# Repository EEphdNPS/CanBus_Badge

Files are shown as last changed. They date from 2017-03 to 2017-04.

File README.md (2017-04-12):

# CanBus_Badge
As we develop a badge for the upcoming event, I will post my eagle files, bill of materials, and source code here.

I developed the board and schematic in Eagle 7.6.0 light.

This board is based on Microchip's AN212 reference design (http://ww1.microchip.com/downloads/en/AppNotes/00212c.pdf)

Overview: The objective of this project is to build a controller area network (CAN) node that can be used during our upcoming hack-a-thon event. Each CAN node is powered by one 9 volt battery. The CAN node has one input and one output. The input is a photoresistor (R12) that is part of a voltage divider. The PIC microcontroller does an analog to digital conversion based on the output of the voltage divider. The CAN node output is a PWM-driven LED (add the part number from the BOM and schematic). The CAN ID of the node is based on the dip switches. The first two switches define the CAN ID when the node transmits the result of the A/D conversion. The last two switches determine which CAN ID the node will receive. The results of A/D conversion are transmitted onto the CAN bus and received by the proper CAN node. The CAN node uses this value to set the pulse width of the on pulse.

5V power regulation:
The current design of the badge uses a 7805 chip to take the 9V battery output and produce 5V for the badge to run. As a note, because the node is powered at 5V, the CAN bus high and low will have a neutral value of 2.5V and the CAN bus high will be 5V and the CAN bus low will be 0V. Added to the power regulation portion of the design is a momentary push button that will indicate whether the badge is on or off. I have not calculated the life of the battery in this application, but during the development of the badge, I've only used one battery and I used one batter to run both nodes that I built. 

PIC 16F876:
The PIC microprocessor is the main chip on the board. The code is (will be) uploaded. The PIC talks to the MCP2515 chip via a SPI interface (pins 3-chip select, 14-SCK, 15-SDI, 16-SDO). Each line of the SPI interface has a test point, which we can use to access the SPI messages during the hack-a-thon. The PIC has one pin (pin 2) for the A/D conversion of the voltage divider. It has one pin (pin 13) as the PWM output. The chip receives a 4 MHz clock signal on pins 9 and 10. Pin 21 on the PIC is connected to the interrupt pin (pin 12) on the MCP2515. Pins 25 and 26 are connected are connected to the receive buffers on the MCP2515. Pins 11, 12, 17, 18 are connected to the DIP switches and are read to determine the transmit CAN ID and which CAN ID will be received. 

MCP2515:
The MCP2515 is the CAN controller chip and handles all CAN messaging. Pins 1 and 2 are connected to the MCP2551. The LEDs off of these lines are used as a visual indication that there is communication between these two chips. There are also test points added to these lines to access the messages being transmitted and received between the two chips. This chip operates with a 16 MHz oscillator on pins 7 and 8. I believe this frequency determines the bit rate on the CAN bus. I added a momentary button to the reset pin because occasionally the chip won't go into normal mode from startup mode. After reading the documentation, the chip needs a bus to be connected before going into normal mode. The reset button let you turn on the node first and then connect it to the bus. Once the bus is connected, I've found that one press of the reset button allows the chip to transition.

MCP2551:
The MCP2551 is a simple chip that interfaces with the CAN bus. This chip is probably not actually needed in this design. I have not tested whether or not it is required. We could probably skip it and connect the MCP2515 directly to another MCP2515 on another node. Pin 6 in the CAN low pin. Pin 7 is the CAN high pin. Pin 8 must be connected to ground via 10K ohm resistor. This pin sets the various modes of the MCP2551 chip. Without this resistor the CAN nodes will not communicate properly. 

CAN Bus:
To build the CAN bus, two 120 ohm resistors are required. These two resistors connect the high and low CAN bus wires at the termination of each end of the bus. At this point, I do not know a limit on the number of nodes that can be added to the bus without significant collisions. I have tested two nodes. If we have more, we could determine the max number that can be added. After trying several different configurations, I've settled on directly connecting the badges. There is no need for the 120 ohm resistors.

I've used the CanaKit UK1300 to program the PICs that I used on my breadboard. The ICSP works on the breadboard I've been developing from. I was not able to test it with Rev 1.0. I used the PICKit 3.

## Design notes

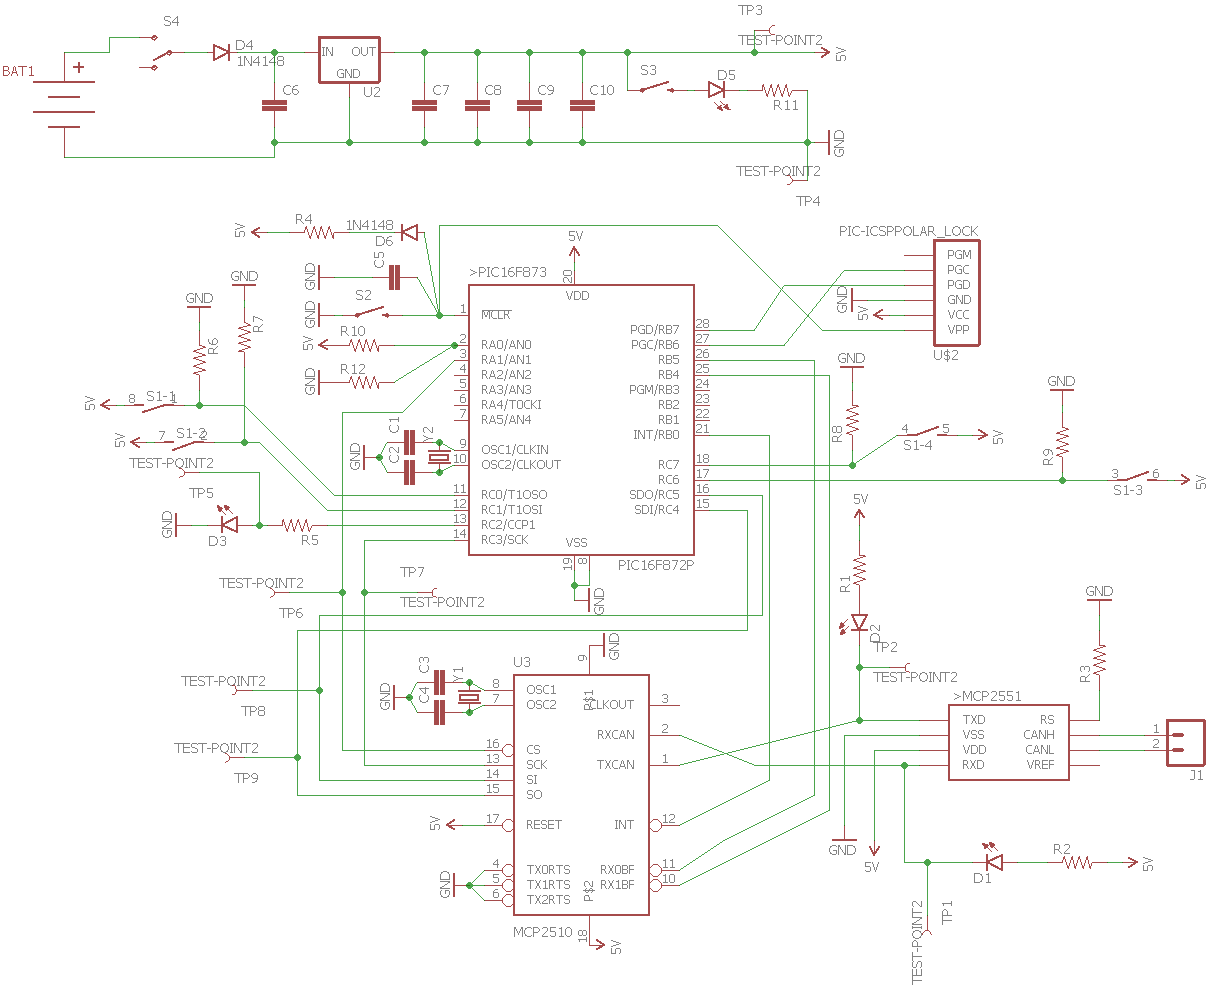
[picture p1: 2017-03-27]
HACKtheMACHINE_schematic.png

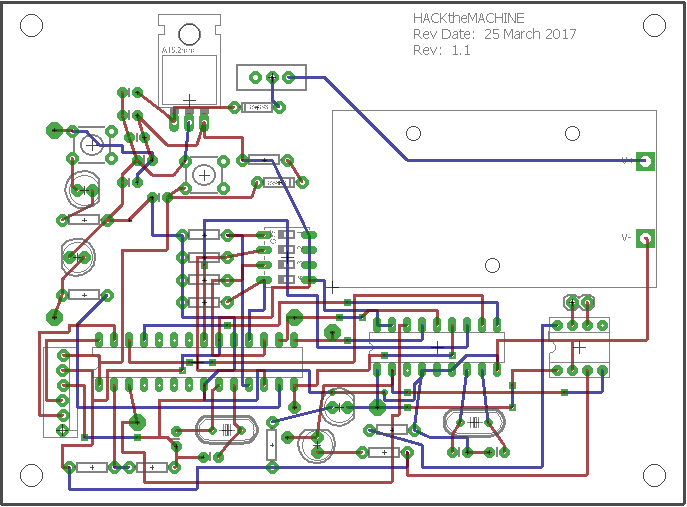
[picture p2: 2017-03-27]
HACKtheMACHINE_board.png

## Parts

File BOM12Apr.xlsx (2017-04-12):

DISCLAIMER: I used whatever parts I had laying around the house. I've listed specific products, but that is only to help with the build. For example, any generic 18 pF capacitor can be used. I also used only digikey to make it easier to find the parts.
Part | Value | Device | Package | Description | MF | MPN | Digi-Key part number | Link to product
BAT1 | N/A | BC9VPC | BC9VPC | 9V board-mount battery cradle | MPD | BC9VPC | BC9VPC-ND | http://www.digikey.com/product-detail/en/mpd-memory-protection-devices/BC9VPC/BC9VPC-ND/257747
C1 | 18 pF | CAPPTH | CAP-PTH-SMALL | 18 pF Ceramic Capacitor | Vishay | K180J15C0GF5TL2 | BC1004TR-ND | https://www.digikey.com/product-detail/en/vishay-bc-components/K180J15C0GF5TL2/BC1004TR-ND/286458
C2 | 18 pF | CAPPTH | CAP-PTH-SMALL | 18 pF Ceramic Capacitor | Vishay | K180J15C0GF5TL3 | BC1004TR-ND | https://www.digikey.com/product-detail/en/vishay-bc-components/K180J15C0GF5TL2/BC1004TR-ND/286458
C3 | 18 pF | CAPPTH | CAP-PTH-SMALL | 18 pF Ceramic Capacitor | Vishay | K180J15C0GF5TL4 | BC1004TR-ND | https://www.digikey.com/product-detail/en/vishay-bc-components/K180J15C0GF5TL2/BC1004TR-ND/286458
C4 | 18 pF | CAPPTH | CAP-PTH-SMALL | 18 pF Ceramic Capacitor | Vishay | K180J15C0GF5TL5 | BC1004TR-ND | https://www.digikey.com/product-detail/en/vishay-bc-components/K180J15C0GF5TL2/BC1004TR-ND/286458
C5 | 0.001 μF | CAPPTH | CAP-PTH-SMALL | 0.001 μF Ceramic Capacitor | Kemet | C320C102K5R5TA | 399-9769-ND | https://www.digikey.com/product-detail/en/kemet/C320C102K5R5TA/399-9769-ND/3726158
C6 | 0.1 μF | CAPPTH | CAP-PTH-SMALL | 0.1 μF Electrolytic Cpacitor | Nichicon | UVR2A0R1MDD | 493-1136-ND | https://www.digikey.com/product-detail/en/nichicon/UVR2A0R1MDD/493-1136-ND/588877
C7 | 10 μF | CAPPTH | CAP-PTH-SMALL | 10 μF Electrolytic Cpacitor | Nichicon | UVR1E100MDD6TP | 493-12772-1-ND | https://www.digikey.com/product-detail/en/nichicon/UVR1E100MDD6TP/493-12772-1-ND/4328365
C8 | 102 pF | CAPPTH | CAP-PTH-SMALL | 102 pF Ceramic Capacitor | Vishay | K101J15C0GF5TL2 | BC1013CT-ND | https://www.digikey.com/product-detail/en/vishay-bc-components/K101J15C0GF5TL2/BC1013CT-ND/286635
C9 | 102 pF | CAPPTH | CAP-PTH-SMALL | 102 pF Ceramic Capacitor | Vishay | K101J15C0GF5TL3 | BC1013CT-ND | https://www.digikey.com/product-detail/en/vishay-bc-components/K101J15C0GF5TL2/BC1013CT-ND/286635
C10 | 102 pF | CAPPTH | CAP-PTH-SMALL | 102 pF Ceramic Capacitor | Vishay | K101J15C0GF5TL4 | BC1013CT-ND | https://www.digikey.com/product-detail/en/vishay-bc-components/K101J15C0GF5TL2/BC1013CT-ND/286635
D1 | N/A | LED5MM | LED5MM | Red LED | Cree | C503B-RCN-CW0Z0AA1 | C503B-RCN-CW0Z0AA1-ND | https://www.digikey.com/product-detail/en/cree-inc/C503B-RCN-CW0Z0AA1/C503B-RCN-CW0Z0AA1-ND/1922930
D2 | N/A | LED5MM | LED5MM | Green LED | Cree | C503B-GCS-CY0C0791 | C503B-GCS-CY0C0791-ND | https://www.digikey.com/product-detail/en/cree-inc/C503B-GCS-CY0C0791/C503B-GCS-CY0C0791-ND/1922941
D3 | N/A | LED5MM | LED5MM | White LED | Cree | C513A-WSS-CY0Z0231 | C513A-WSS-CY0Z0231-ND | https://www.digikey.com/product-detail/en/cree-inc/C513A-WSS-CY0Z0231/C513A-WSS-CY0Z0231-ND/5120069
D4 | N/A | DIODEKIT | DIODE-1N4148-KIT | Diode | Sanken | EM01ZV1 | EM01ZV1CT-ND | https://www.digikey.com/product-detail/en/sanken/EM01ZV1/EM01ZV1CT-ND/4572558
D5 | N/A | LED5MM | LED5MM | Blue LED | Cree | C503B-BCN-CV0Z0461 | C503B-BCN-CV0Z0461-ND | https://www.digikey.com/product-detail/en/cree-inc/C503B-BCN-CV0Z0461/C503B-BCN-CV0Z0461-ND/1922945
D6 | N/A | DIODEKIT | DIODE-1N4148-KIT | Diode | Sanken | EM01ZV1 | EM01ZV1CT-ND | https://www.digikey.com/product-detail/en/sanken/EM01ZV1/EM01ZV1CT-ND/4572558
IC1 | N/A | PIC16F872P | DIL28-3 | MICROCONTROLLER | MICROCHIP | PIC16F873-20/SP | PIC16F873-20/SP-ND | https://www.digikey.com/products/en?keywords=PIC16F873-20%2FSP
J1 | 2 pin header | M02PTH | 1X02 | Standard 2-pin 0.1 header | Sullins connector solutions | PPTC021LFBN-RC | S7000-ND | https://www.digikey.com/product-detail/en/sullins-connector-solutions/PPTC021LFBN-RC/S7000-ND/810142
R1 | 1k Ω | RESISTOREZ | AXIAL-0.3EZ | 1k Ω resistor
R2 | 1k Ω | RESISTOREZ | AXIAL-0.3EZ | 1k Ω resistor
R3 | 10k Ω | RESISTOREZ | AXIAL-0.3EZ | 10k Ω resistor
R4 | 47k Ω | RESISTOREZ | AXIAL-0.3EZ | 47k Ω resistor
R5 | 1k Ω | RESISTOREZ | AXIAL-0.3EZ | 1k Ω resistor
R6 | 10k Ω | RESISTOREZ | AXIAL-0.3EZ | 10k Ω resistor
R7 | 10k Ω | RESISTOREZ | AXIAL-0.3EZ | 10k Ω resistor
R8 | 10k Ω | RESISTOREZ | AXIAL-0.3EZ | 10k Ω resistor
R9 | 10k Ω | RESISTOREZ | AXIAL-0.3EZ | 10k Ω resistor
R10 | 47k Ω | RESISTOREZ | AXIAL-0.3EZ | R10 and R12 are part of a voltage divider. Adjust R10 to get a good dynamic range based on the range of R12.
R11 | 1k Ω | RESISTOREZ | AXIAL-0.3EZ | 1k Ω resistor
R12 | ~300 to 50k Ω | RESISTORAXIAL-0.3 | AXIAL-0.3 | Photoresistor Optoresistor Photo Light Sensitive Resistor | Luna Optoelectronics | PDV-P8103 | PDV-P8103-ND | https://www.digikey.com/product-detail/en/luna-optoelectronics/PDV-P8103/PDV-P8103-ND/480610
S1 | Dip Switch | DIP04S | DIP04S | 4 switches set the receiver and transmit CAN ID | CTS | 206-4ST | CT2064ST-ND | https://www.digikey.com/product-detail/en/cts-electrocomponents/206-4ST/CT2064ST-ND/20774
S2 | Momentary Push Button | SWITCH-MOMENTARY-2PTH | TACTILE-PTH | Tactile push button | TE Connectivity ALCOSWITCH Switches | 1825910-6 | 450-1650-ND | https://www.digikey.com/product-detail/en/te-connectivity-alcoswitch-switches/1825910-6/450-1650-ND/1632536
S3 | Momentary Push Button | SWITCH-MOMENTARY-2PTH | TACTILE-PTH | Tactile push button | TE Connectivity ALCOSWITCH Switches | 1825910-6 | 450-1650-ND | https://www.digikey.com/product-detail/en/te-connectivity-alcoswitch-switches/1825910-6/450-1650-ND/1632536
S4 | SPDT switch | SWITCH-SPDTKIT | SWITCH-SPDT_KIT | On/Off Switch | E-Switch | EG1218 | EG1903-ND | https://www.digikey.com/product-detail/en/e-switch/EG1218/EG1903-ND/101726
S5 | Momentary Push Button | SWITCH-MOMENTARY-2PTH | TACTILE-PTH | Tactile push button | TE Connectivity ALCOSWITCH Switches | 1825910-6 | 450-1650-ND | https://www.digikey.com/product-detail/en/te-connectivity-alcoswitch-switches/1825910-6/450-1650-ND/1632536
TP1 | TEST-POINT2 | TEST-POINT2 | PAD.02X.02 | Receive CAN between MCP2515 and MCP2551
TP2 | TEST-POINT2 | TEST-POINT2 | PAD.02X.02 | Transmit CAN between MCP2515 and MCP2551
TP3 | TEST-POINT2 | TEST-POINT2 | PAD.02X.02 | 5 volt/power test point
TP4 | TEST-POINT2 | TEST-POINT2 | PAD.02X.02 | Ground test point
TP5 | TEST-POINT2 | TEST-POINT2 | PAD.02X.02 | PWM output test point
TP6 | TEST-POINT2 | TEST-POINT2 | PAD.02X.02 | Chip Select Line between PIC and MCP2515
TP7 | TEST-POINT2 | TEST-POINT2 | PAD.02X.02 | Clock between PIC and MCP2515
TP8 | TEST-POINT2 | TEST-POINT2 | PAD.02X.02 | Slave Input between PIC and MCP2515
TP9 | TEST-POINT2 | TEST-POINT2 | PAD.02X.02 | Slave Output between PIC and MCP2515
U$1 | MCP2551 | MCP2551 | DIL8 | CAN controller with SPI interface to any MCU. | MICROCHIP | MCP2551-I/P | MCP2551-I/P-ND | https://www.digikey.com/product-detail/en/microchip-technology/MCP2551-I-P/MCP2551-I-P-ND/509453
U$2 | 6 pin header | ICSP header | 6-pin header | Standard 6-pin 0.1 header | Samtec | SSA-106-S-T | SAM1122-06-ND | https://www.digikey.com/product-detail/en/samtec-inc/SSA-106-S-T/SAM1122-06-ND/1105810
U2 | 5 volt regulator | V_REG_78XXSIDE | L7805 | Voltage Regulator | STMicroelectronics | L7805CV | 497-1443-5-ND | https://www.digikey.com/product-detail/en/stmicroelectronics/L7805CV/497-1443-5-ND/585964
U3 | MCP2515 | MCP2515 | DIL18 | CAN controller with SPI interface to any MCU. | MICROCHIP | MCP2515-I/P | MCP2515-I/P-ND | https://www.digikey.com/product-detail/en/microchip-technology/MCP2515-I-P/MCP2515-I-P-ND/593000
Y1 | 16 MHz | CRYSTALHC49UV | HC49U-V | Oscillator for MCP2510 | ECS inc | ECS-160-20-4X-DU | XC1925-ND | https://www.digikey.com/product-detail/en/ecs-inc/ECS-160-20-4X-DU/XC1925-ND/2781930
Y2 | 4 MHz | CRYSTALHC49UV | HC49U-V | Oscillator for PIC | ECS inc | ECS-40-18-4XEN | XC1735-ND | https://www.digikey.com/product-detail/en/ecs-inc/ECS-40-18-4XEN/XC1735-ND/2213755

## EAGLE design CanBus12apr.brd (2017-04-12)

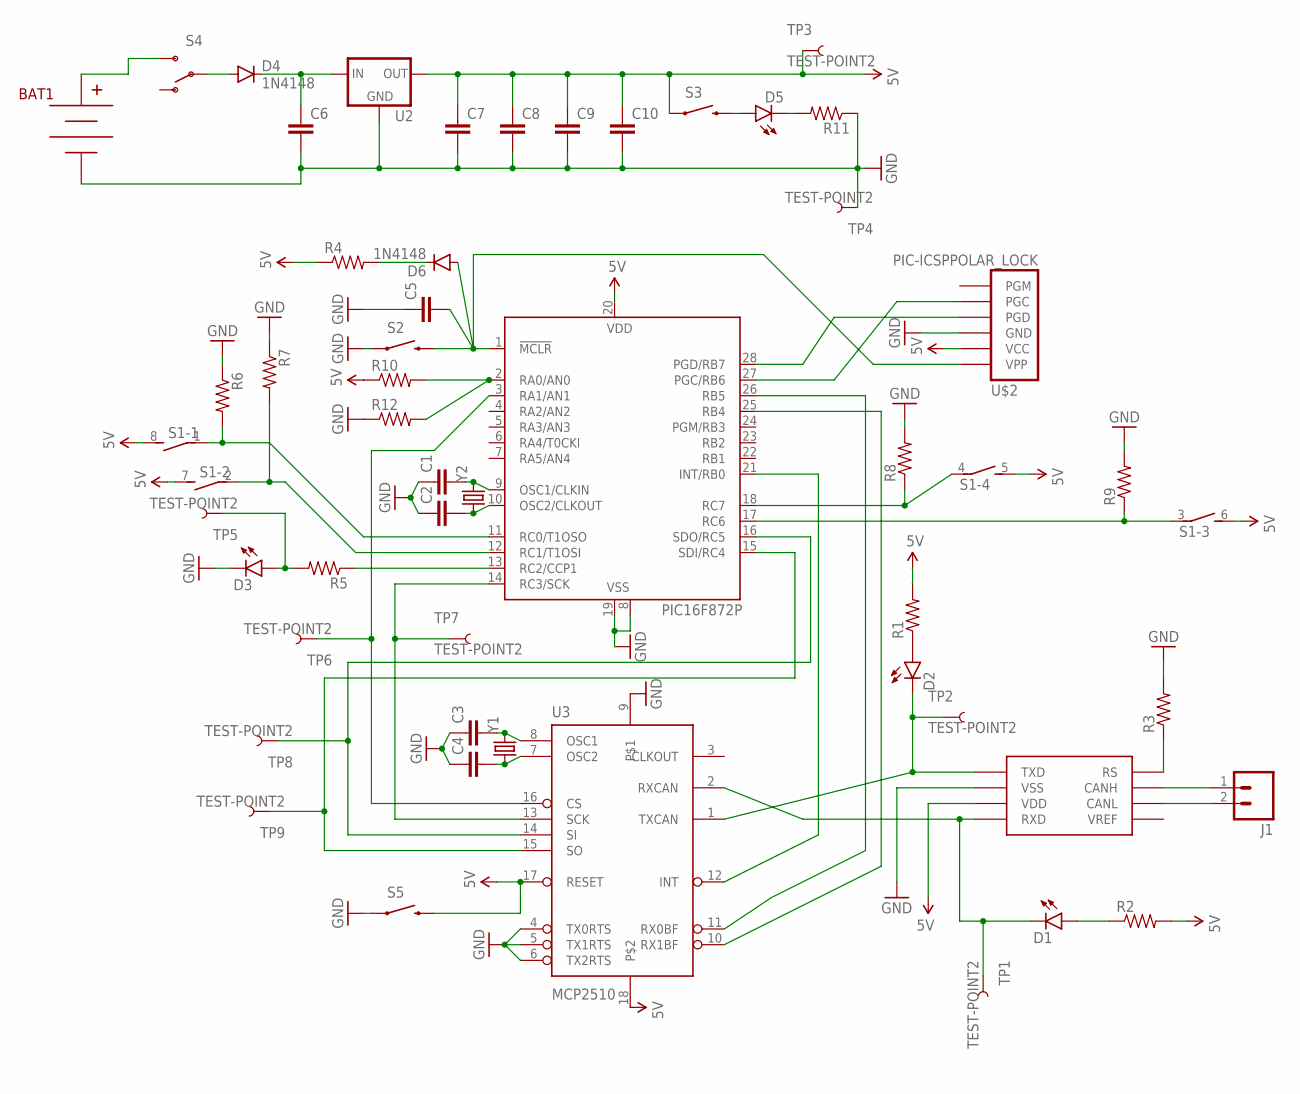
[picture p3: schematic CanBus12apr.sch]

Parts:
BAT1: BC9VPC
C1, C2, C3, C4, C5, C6, C7, C8, C9, C10: CAPPTH; CAP-PTH-SMALL
D1, D2, D3, D5: LED5MM
D4, D6: 1N4148; DIODE-1N4148-KIT
IC1: PIC16F872P; DIL28-3
J1: M02PTH; 1X02
R1, R2, R3, R4, R5, R6, R7, R8, R9, R10, R11: RESISTOREZ; AXIAL-0.3EZ
R12: RESISTORAXIAL-0.3; AXIAL-0.3
S1: DIP04S
S2, S3, S5: SWITCH-MOMENTARY-2PTH; TACTILE-PTH
S4: SWITCH-SPDTKIT; SWITCH-SPDT_KIT
TP1, TP2, TP3, TP4, TP5, TP6, TP7, TP8, TP9: TEST-POINT2; PAD.02X.02
U2: V_REG_78XXSIDE; 78XXL
U3: MCP2510; DIL18
U$1: MCP2551
U$2: PIC-ICSPPOLAR_LOCK; MOLEX-1X6_LOCK
Y1, Y2: CRYSTALHC49UV; HC49U-V

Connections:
5V: C7.1, C8.1, C9.1, C10.1, IC1.20 (VDD), R1.P$2 (2), R2.P$2 (2), R4.P$1 (1), R10.P$1 (1), S1.5 (2), S1.6 (2), S1.7 (2), S1.8 (2), S3.1, S5.3 (2), TP3.P$1, U2.OUT, U3.17 (RESET), U3.18, U$1.VDD, U$2.5 (VCC)
GND: BAT1.V-, C1.1, C2.1, C3.1, C4.1, C5.1, C6.2, C7.2, C8.2, C9.2, C10.2, D3.K (C), IC1.8 (VSS), IC1.19 (VSS), R3.P$2 (2), R6.P$1 (1), R7.P$1 (1), R8.P$2 (2), R9.P$2 (2), R11.P$1 (1), R12.P$1 (1), S2.1, S5.1, TP4.P$1, U2.GND, U3.4 (TX0RTS), U3.5 (TX1RTS), U3.6 (TX2RTS), U3.9, U$1.VSS, U$2.4 (GND)
unnamed: D1.K (C), TP1.P$1, U3.2 (RXCAN), U$1.RXD
unnamed: D2.K (C), TP2.P$1, U3.1 (TXCAN), U$1.TXD
unnamed: D2.A, R1.P$1 (1)
unnamed: D1.A, R2.P$1 (1)
unnamed: IC1.21 (INT/RB0), U3.12 (INT)
unnamed: IC1.26 (RB5), U3.11 (RX0BF)
unnamed: IC1.25 (RB4), U3.10 (RX1BF)
unnamed: IC1.11 (RC0/T1OSO), R6.P$2 (2), S1.1
unnamed: R3.P$1 (1), U$1.RS
unnamed: IC1.2 (RA0/AN0), R10.P$2 (2), R12.P$2 (2)
unnamed: C3.2, U3.8 (OSC1), Y1.2
unnamed: C4.2, U3.7 (OSC2), Y1.1
unnamed: C1.2, IC1.9 (OSC1/CLKIN), Y2.2
unnamed: C2.2, IC1.10 (OSC2/CLKOUT), Y2.1
unnamed: IC1.14 (RC3/SCK), TP7.P$1, U3.13 (SCK)
unnamed: IC1.16 (SDO/RC5), TP8.P$1, U3.14 (SI)
unnamed: IC1.15 (SDI/RC4), TP9.P$1, U3.15 (SO)
unnamed: IC1.3 (RA1/AN1), TP6.P$1, U3.16 (CS)
unnamed: C5.2, D6.A, IC1.1 (!MCLR!), S2.3 (2), U$2.6 (VPP)
unnamed: IC1.13 (RC2/CCP1), R5.P$1 (1)
unnamed: D3.A, R5.P$2 (2), TP5.P$1
unnamed: IC1.27 (PGC/RB6), U$2.2 (PGC)
unnamed: IC1.12 (RC1/T1OSI), R7.P$2 (2), S1.2 (1)
unnamed: IC1.17 (RC6), R9.P$1 (1), S1.3 (1)
unnamed: IC1.18 (RC7), R8.P$1 (1), S1.4 (1)
unnamed: BAT1.V+, S4.3 (S)
unnamed: C6.1, D4.C, U2.IN
unnamed: D5.K (C), R11.P$2 (2)
unnamed: D4.A, S4.2
unnamed: D5.A, S3.3 (2)
unnamed: J1.1, U$1.CANH
unnamed: J1.2, U$1.CANL
unnamed: IC1.28 (PGD/RB7), U$2.3 (PGD)
unnamed: D6.C, R4.P$2 (2)

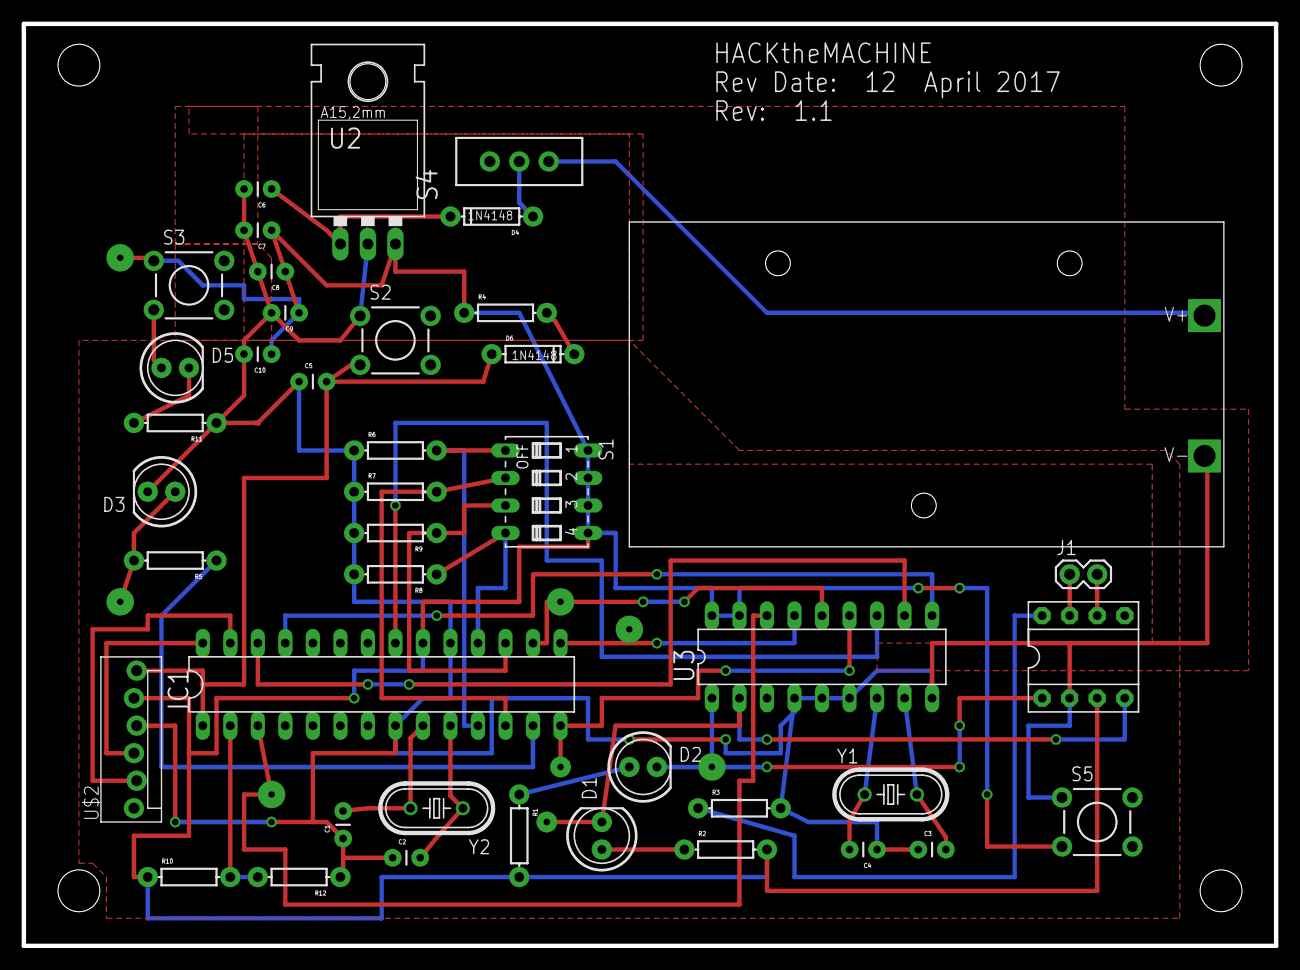
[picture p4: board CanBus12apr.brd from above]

Board: 2 copper layers, 115.6 x 85.1 mm, 51 parts (0 on the bottom side), 36 nets.

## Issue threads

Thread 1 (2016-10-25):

Eagle Design Review

zacsketches, 2016-10-25:
James, please take a look at the board and schematic for this project.

Zac

Closed 2017-03-21.

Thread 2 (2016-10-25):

README needs to be more descriptive

zacsketches, 2016-10-25:
Tom, I think it would help James if the README was written from the perspective of someone completely new to this board. Right now it requires some inside knowledge of our conversations about how to design it.

Thoughts?

EEphdNPS, 2016-10-25:
Can do.

EEphdNPS, 2016-10-27:
I've added a lot more detail. Let me know if this is good enough.

Closed 2016-10-27.

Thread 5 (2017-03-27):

Eliminate the 9 volt battery

EEphdNPS, 2017-03-27:
I would like to use smaller, coin batteries like the CR2032.

EEphdNPS, 2017-04-03:
I bought a battery holder for the CR2032. I'm waiting on the batteries to arrive.

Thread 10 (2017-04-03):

add momentary button to reset mcp2515

EEphdNPS, 2017-04-03:
Sometimes the canbus hangs and needs to be reset. A reset button on the mcp2515 will probably do the trick.

Closed 2017-04-12.

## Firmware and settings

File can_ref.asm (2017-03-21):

;*******************************************************************
; Microchip CAN Reference Design
;
; Mike Richitelli
; Diversified Engineering
; 283 Indian River Road
; Orange, CT 06477
; (203)799-7875 fax(203)799-7892
; WWW.DIVERSIFIEDENGINEERING.NET 
;
;*******************************************************************
;*******************************************************************

          TITLE " CAN_Ref Design "

;*******************************************************************

dVersion       equ  1
dRelease       equ  5

;======================================================================
; Transmits CAN message every 131 mSec.  Message contains two data bytes
;         that represent a 12 bit value with least significant byte
;         sent first.
; Cycles between three outputs:
;         Pot:  Value goes from 0 to 0xFF0 as Pot is turned clockwise.
;               ID is selected from DIP switches #3 and #4 as follows:
;                   #3 #4  ID
;                   0  0   transmission disabled 
;                   0  1   0x100
;                   1  0   0x200
;                   1  1   0x300
;
;         Push button switch: Switch open => 0, Switch closed => 0xFFF   
;               ID is Pot ID + 0x010
;
;         CdS:  Value goes from 0 to 0xFF0 as Pot is turned clockwise.
;               ID is Pot ID + 0x020
;
; CAN messages received are assumed to be 12 bit data sent as two bytes, 
;         least significant byte first.
;
;         The base ID for receiving CAN messages is specified by DIP 
;         switches #1 and #2:
;                   #1 #2  ID
;                   0  0   0x000
;                   0  1   0x100
;                   1  0   0x200
;                   1  1   0x300
;
;         Lamp: If the message ID matches the ID selected by the DIP 
;               switches the 12 bit data is used to generate a PWM output 
;               where a 0 value gives a zero duty cycle and 0xFFF generates 
;               a 100% duty cycle.  The lamp output is proportional to
;               the duty cycle.
;               ID is Base ID
;
;         LED: On if value received is >= 0x800 and off if < 0x800.
;               ID is Base ID + 0x010
;
;======================================================================

;----- PIC16F876 Micro -----;

          LIST P=16F876
          LIST r=dec,x=on,t=off

#include "P16F876.INC"

  __CONFIG _BODEN_ON&_CP_OFF&_WRT_ENABLE_ON&_PWRTE_ON&_WDT_OFF&_HS_OSC&_DEBUG_OFF&_CPD_OFF&_LVP_OFF
  __IDLOCS (dVersion<<8)|dRelease  ; version: vvrr , vv- version, rr - release

;---------------------------;

#include "MACROS16.INC"
#include "MCP2510.INC"

;          errorlevel 0,-306,-302,-305

 
;******** constants

;Crystal freq 4.00 MHz, Fosc/4 = 1 uS
;
; Timer 1: Uses no prescale => Tic is 1 uSec
;       8 bit rollover 256 uSec
;       16 bit rollover 65.536 mSec

;   8 bit timers
;    TMR1L: 1 uSec tics with maximum of 1/2 rollover = 128 uSec maximum
;    TMR1H: 256 uSec tics with maximum of 1/2 rollover = 32.768 msec maximum



;======================================================================

;************************
; A/D selection ( value of ADCON0 )

#define dA2DRA0     B'01000000'         ; fosc/8 clk, RA0, A/D off
#define dA2DRA3     B'01011000'         ; fosc/8 clk, RA3, A/D off


;************************
; special function defines

#define _SSPEN      SSPCON,SSPEN        ; SPI enable

;************************

;; General control flags definitions

#define tbWork          bGenFlags1,0   ; working bit
#define tbReset         bGenFlags1,1   ; must reset 
#define tbNewSPI        bGenFlags1,2   ; new SPI data available
#define tbRxMsgPend     bGenFlags1,3   ; new CAN message received
#define tbTxMsg         bGenFlags1,4   ; xmit next CAN message
#define tbRC2NowHigh    bGenFlags1,5   ; Robot PWM signal high


;*****************  PIN DEFINITIONS **************************

#define tp2510_CS_   PORTA,1       ; CS_ for 2510 chip

;; I/O 
#define tpSwitch_    PORTB,1       ; Push button switch, Open => high
#define tpLED        PORTB,2       ; LED 

;; Analog In 
#define tpA2D_CS_    PORTB,1       ; CS_ for 3201 A2D chip
#define tpEE_CS_     PORTB,2       ; CS_ for 25040 E2

;*****************  LOCAL REGISTER STORAGE **************************
;
;
;============ BANK 0 =================

 cblock   0x20
     ;; interrupt variables
          bIntSaveSt       ; save Status
          bIntSaveFSR      ; save FSR
          bIntSavPCLATH    ; interrupt storage for PCLATH
          bIntWork         ; working
          iIntWork:2       ; working

     ;; general work space
	bGenFlags1       ; general control flags 1
	bGenFlags2       ; general control flags 2
          bWork            ; work byte
          bWork1           ; work byte 
	iWork:2          ; work integer
	bCnt             ; work byte counter

     ;; Arithmetic
          iA:2             ; 2 byte integer
          iB:2             ; 2 byte integer

     ;; Timer1
          iTimer1:2        ; counts Timer1 rollover   
          bGenClk          ; general clock    
          bXmitClk         ; Countdown to xmit next message

     ;; In/Out variables
          iA2DValue:2      ; 12 bit or 8 bit A2D value   
          bPWMValue        ; 8 bit PWM value   
          iRecValue:2      ; 12 bit received value

     ;; general control
          bSwXmitID        ; ID for transmission from DIP switch
          bBaseRecID       ; ID for reception from DIP switch
          bRecIDNext       ; Rec Base ID + 1
          bXmitID          ; ID for transmission of next msg
          bNextMsgType     ; Select next msg

     ;; Received CAN message
          iRecID_L         ; ID of received message (3 bits left justified)
          iRecID_H         ; ID of received message (8 bits left justified)
          bRecCount        ; number of bytes received
          pRecDataBase:8   ; received data

     ;; Low level SPI interface
          b2510RegAdr      ; Register address
          b2510RegData     ; Data sent/received
          b2510RegMask     ; Bit Mask

       ; following used in interrupt      
          bSPICnt          ; # bytes remaining to receive
          pSPIBuf          ; Pointer into buffer   
          pSPIBufBase:12   ; Base of SPI receive/xmit buffer

 endc


; storage for interrupt service routine
; W saved in one of these locations depending on the page selected 
; at the time the interrupt occured

bIntSaveW0 equ  0x7F       ; interrupt storage for W

;============ BANK 1 =================
bIntSaveW1 equ  0xFF       ; interrupt storage for W

;*******************************************************************
;********** LOCAL MACROS *******************************************
;*******************************************************************
; 
; Shift left 2 byte integer once.
iShiftL macro    iVar
        bcf      _C                ; clear carry bit    
        rlf      iVar,F
        rlf      iVar+1,F
        endm
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

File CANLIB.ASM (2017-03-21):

;**********************************************************
;**********************************************************


; MCP2510 Instructions
#define d2510Rd      0x03      ; MCP2510 read instruction
#define d2510Wrt     0x02      ; MCP2510 write instruction
#define d2510Reset   0xC0      ; MCP2510 reset instruction
#define d2510RTS     0x80      ; MCP2510 RTS instruction
#define d2510Status  0xA0      ; MCP2510 Status instruction
#define d2510BitMod  0x05      ; MCP2510 bit modify instruction



;**********************************************************
;*************** SPECIAL CAN MACROS ***********************
;**********************************************************

; Read 2510 register Reg and return data in W.
SPI_Read macro Reg
          movlw     Reg
          call      Rd2510Reg
          endm

; Write literal byte to 2510 register Reg.
SPI_WriteL macro Reg,LitData
          movlw     LitData
          movwf     b2510RegData
          movlw     Reg
          call      Wrt2510Reg
          endm

; Write Data byte to 2510 register Reg.
SPI_WriteV macro Reg,RegData
          movfw     RegData
          movwf     b2510RegData
          movlw     Reg
          call      Wrt2510Reg
          endm

; Write W byte to 2510 register Reg.
SPI_WriteW macro Reg
          movwf     b2510RegData
          movlw     Reg
          call      Wrt2510Reg
          endm


; Write bits determined by Mask & Data to 2510 register Reg.
SPI_BitMod macro Reg,Mask,Data
          movlw     Mask
          movwf     b2510RegMask
          movlw     Data
          movwf     b2510RegData
          movlw     Reg
          call      BitMod2510
          endm

; Arm xmit buffers for xmission
SPI_Rts macro Data
          movlw     Data
          call      Rts2510
          endm


;**********************************************************
;**********************************************************
;Support routines for communicating with 2510 chip
;**********************************************************
;**********************************************************

;******************************************************
;CheckCANMsg
;
; Checks for message in Receive Buf 1.  If no message pending return
; with Z flag set.
;         
; If message pending:
;     Load iRecID_L,iRecID_H with ID.
;     Load bRecCount with number of bytes of data received.
;     Load buffer at pRecDataBase with data
;     Clear 2510 Receive Buffer 1 interrupt flag
;     Set tbRxMsgPend flag and clear Z flag.
;
; NOTE: If message already pending doesn't check for new message.
;
;******************************************************/
CheckCANMsg

          bcf       _Z                  ; for return
          skipClr   tbRxMsgPend         ; new CAN message received
          return                        ; Message already pending

     ;; Test for Message pending in Receive Buffer 1
          SPI_Read  CANINTF
          andlw     0x02      

          skipNZ
          return              ; Nothing in Rec Buf 1

          bsf       tbRxMsgPend         ; new CAN message received

     ;; Get ID of message source 
          SPI_Read  RXB1SIDH
          movwf     iRecID_H
          SPI_Read  RXB1SIDL
          andlw     0xE0
          movwf     iRecID_L

     ;; Get number of bytes of data
          SPI_Read  RXB1DLC
          andlw     0x0F
          movwf     bRecCount

     ;; Get data from buffer. Up to 8 bytes based on 
          clrf      bCnt

jRxChk11  jmpFeqF   bCnt,bRecCount,jRxChk90            ; no data left

     ;; Calculate correct 2510 receive buffer location
          movlw     RXB1D0
          addwf     bCnt,W

     ;; Get data byte
          call      Rd2510Reg
          movwf     b2510RegData     ; temporary save

     ;; Calculate destination buffer location
          movlw     pRecDataBase
          addwf     bCnt,W
          movwf     FSR

     ;; Store data in buffer
          movfw     b2510RegData     ; temporary save
          movwf     INDF
          incf      bCnt,F
          goto      jRxChk11

jRxChk90
          SPI_BitMod CANINTF,0x02,0     ; Clear receive buffer 1 interrupt
          bcf       _Z                  ; signal data pending
          return


;**********************************************************
;SetConfigMode
;
;// Function Name: Set_Config_Mode()
;**********************************************************
SetConfigMode
;  SPI_BitMod(CANCTRL, 0xE0, 0x80);    //Config. mode/
          bL2bV     0xE0,b2510RegMask
          bL2bV     0x80,b2510RegData
          movlw     CANCTRL
          call      BitMod2510

jSetConfigM1
          movlw     CANSTAT
          call      Rd2510Reg
          andlw     0xE0
          xorlw     0x80
          jmpNZ     jSetConfigM1

          return


;**********************************************************
;SetNormalMode
;
;// Function Name: Set_Normal_Mode()
;**********************************************************
SetNormalMode

          bL2bV     0xE0,b2510RegMask
          bL2bV     0x00,b2510RegData
          movlw     CANCTRL
          call      BitMod2510

jSetNormalM1
          movlw     CANSTAT
          call      Rd2510Reg
          andlw     0xE0
          jmpNZ     jSetNormalM1

          return

;**********************************************************
;WaitANDeqZ
;         Wait for byte from address in W to AND with mask in
;         b2510RegMask to be zero. Uses b2510RegAdr to hold address.
;         
;**********************************************************
WaitANDeqZ
          movwf     b2510RegAdr         ; save

jWaitANDeqZ
          movfw     b2510RegAdr         ; save
          call      Rd2510Reg
          andwf     b2510RegMask,W
          jmpNZ     jWaitANDeqZ
          return


;**********************************************************
;**********************************************************


;**********************************************************
;**************** BASIC COMMUNICATION *********************
;**********************************************************


;**********************************************************
;Get2510Status
;         Get Status byte from 2510.
;// Function Name: SPI_ReadStatus()
;**********************************************************
Get2510Status
          call      InitSPIBuf
          movlw     d2510Status          ; MCP2510 Status instruction
          call      LoadSPIByte
          movlw     1                   ; expect 1 byte answer
          call      LoadSPIZeros
          call      ExchangeSPI
          call      WaitSPIExchange
          return
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

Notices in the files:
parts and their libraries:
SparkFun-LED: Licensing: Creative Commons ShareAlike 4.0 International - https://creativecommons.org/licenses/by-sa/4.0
